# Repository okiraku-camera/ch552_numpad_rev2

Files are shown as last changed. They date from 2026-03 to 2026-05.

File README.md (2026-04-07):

# CH552 Numeric Keypad revision 2

English version is here: [README_en.md](README_en.md)

このリポジトリは、CH552Gマイクロコントローラを使ったシンプルなUSBテンキーを作成するためのハードウェアの作成情報と、このハードウェアを動作させるためのキーボード用ソフトウェアについての情報を含んでいます。

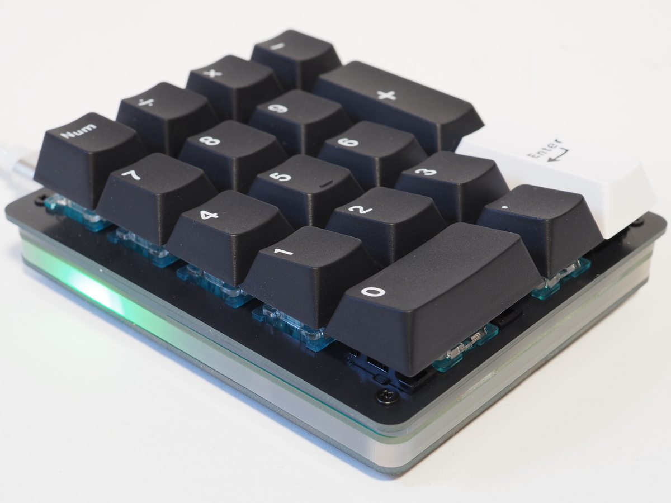
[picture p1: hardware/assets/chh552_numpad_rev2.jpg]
ch5552_numpad_rev2


## ハードウェア
**KiCad 6.0**用のファイル一式、製造に用いたガーバーファイル、アクリルカットのための DXF および PDFファイルが、hardware ディレクトリ内に入っています。

## ソフトウェア
上記のハードウェア用に記述した、マクロキーボードにもなるテンキーです。コアパッケージとして **ch55xDuino** (v0.25) を用いた Arduino 用のスケッチです。また、Arduinoのlibrariesディレクトリに `ch552_keyPad_Library` を配置しておく必要があります。

- `macro_numpad/` : マクロテンキーのファームウェアスケッチ
- `html/` : WebHID 設定用 Web UI (macro_numpad.html)

### webhid を使ったマクロキーボードの実装 (macro_numpad)
テンキーの17キーのうち、NumLock を除いた16キーに、**WebHID** を使って好きな UsageID を割り当てられるようにしています。

メディア操作やマウス操作など、ちょっと特別なコードも設定できます。また、1つのキーに複数の UsageID をまとめて登録できるので、ワンアクションで複数のキー入力をまとめて実行することもできます。

WebHIDのサンプル的な意味合いで記述しました。

### マクロキーボードの設定用webアプリケーション (htmlおよびjavascript)
マクロキーボードとWebHIDで通信し、ブラウザに表示する仮想キーボードとデバイス間とでコードの書込みや読出しを行うためのWebアプリケーションです。

## ライセンス
This project contains hardware and software components.

Copyright (c) Takeshi Higasa, okiraku-camera.tokyo

See [LICENSE](./LICENSE)

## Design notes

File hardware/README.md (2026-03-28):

# ハードウェアについて

English version is here: [README_en.md](README_en.md)

CH552Gマイクロコントローラを使ったシンプルなUSBテンキーです。

このプロジェクトには、PCB、FR-4を使ったプレート、アクリル板を使ったポート部品の、KiCad設計ファイルが含まれています。

製造およびアクリルカットに用いたgerber、DXF、およびPDFファイルも含んでいます。

ハードウェアの設計はKiCAD 6.0で行いました。各ディレクトリ内のKiCADプロジェクトファイルを開くことで、回路構成、PCB構成、各プレートの設計内容を見ることができます。

## PCBおよびプレート
PCB、スイッチをはめ込むtop_plate、底板となる bottom_plate は、材質はFR-4で製造時の厚さ指定は1.6mmです。

### PCB
chh552g を使ったふつうのテンキーを作成するためのPCBです。4列5行構成のスイッチマトリックス回路で、17個のMX互換スイッチを使います。スイッチの取付けには Keilh のスイッチソケット (Hotswap socket) を利用します。

PCBの厚さは1.6mm、PCBのネジ穴径は3mmです。このネジ穴にはM2用の真鍮スペーサーが (途中まで) 入ります。

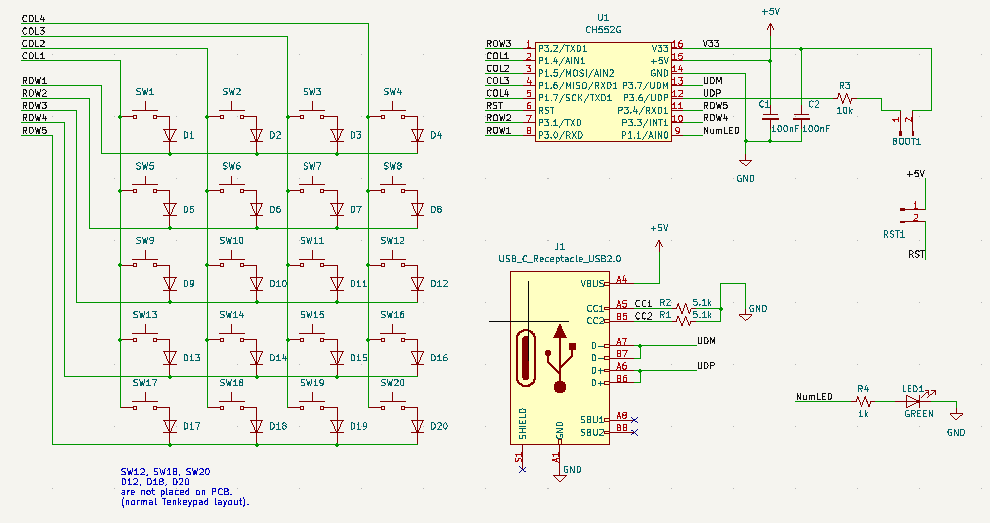
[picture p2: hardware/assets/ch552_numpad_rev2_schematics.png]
回路図

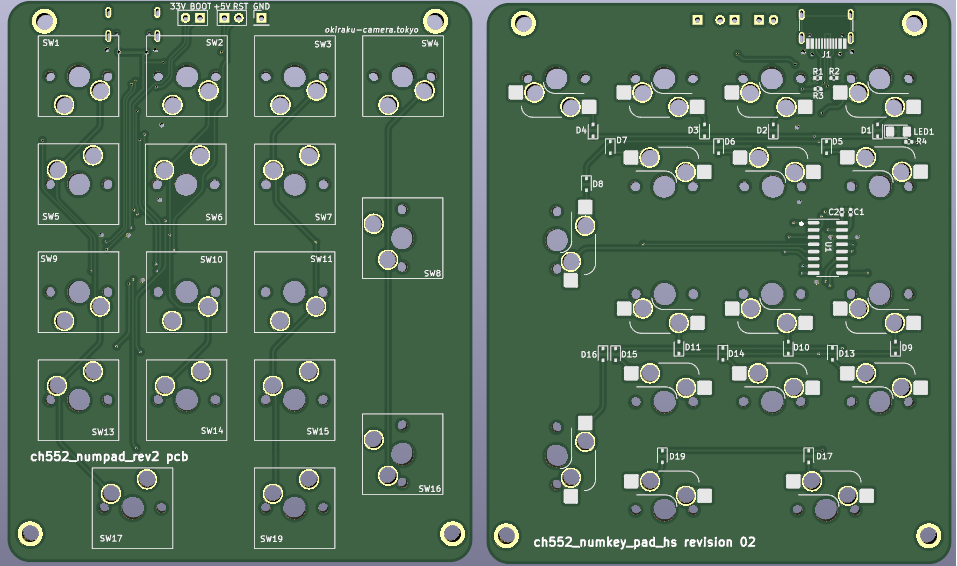
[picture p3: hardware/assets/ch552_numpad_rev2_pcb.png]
PCB


### top_plate
MXスイッチをマウントするためのスイッチプレートです。各スイッチは、13.9mm角の矩形にはめ込みます。MXスイッチの仕様的には14mm角の矩形が求められていますが、実際にスイッチをはめると緩かったりガタつくことがあるので、小さ目にしています。

今回のキーボードはCherryスタイルのプレートマウントスタビライザーを用いるため、そのためのフットプリントを用意しました。

スイッチをはめ込むためのホールは、今回の設計では単純な矩形としていますが、半径0.5mm程度の円弧で丸めた方が割れを防ぐ面で安全です。

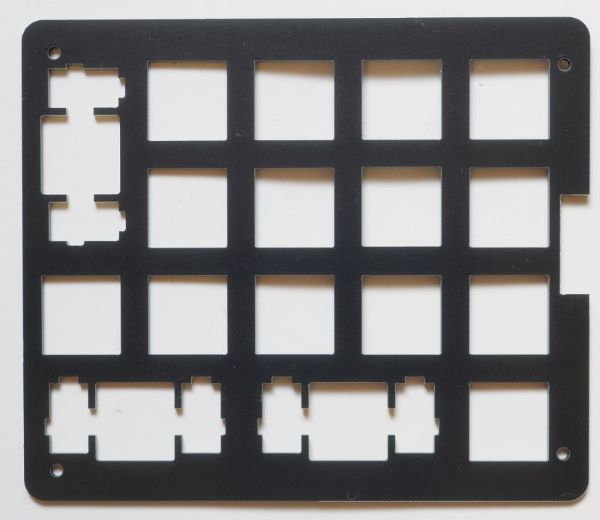
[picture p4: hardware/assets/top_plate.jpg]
top_plate F面


プレートの厚さ1.5mm、ネジ穴径は2.4mmです。

### bottom_plate
キーボードの底板になります。1.6mmのPCBを指定し、B面は導体ゾーンと塗りつぶし禁止エリアを組み合わせた市松模様にしました。

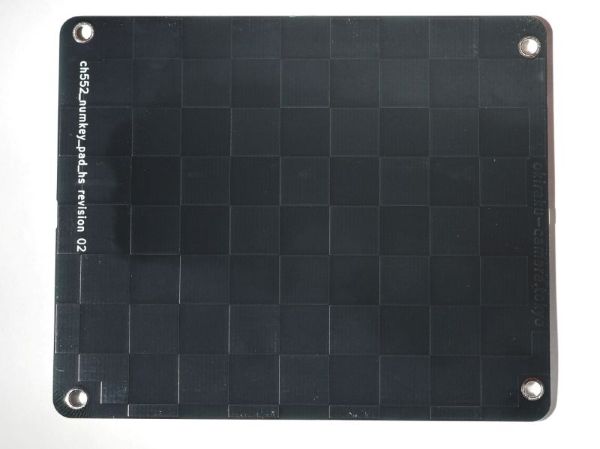
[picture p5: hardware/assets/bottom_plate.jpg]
bottom_plate B面


ネジ穴径は3mmです。

### 注意点

top_plate\libに含まれている プレートマウントスタビライザー用のフットプリント (MX_Plate_Mount_Stabilizer_2U.kicad_mod) と、M2ネジのマウントホール用フットプリント (MountingHole_M2.kicad_mod) にコートヤードを設定しなかったため、Enterキー用のスタビライザーの一部がネジ穴に干渉します。実装後にスタビライザーの一部を切り取ることで対処可能です。

### アクリルサポート
3枚のプレート (PCB, top, bottom) 間のクリアランスを確保するための、アクリル板によるサポート部材です。アクリル板の厚さや部材(透明、半透明、色など) はアクリルカットをやってくれる業者 (Elecrow社など) に対して指定しています。

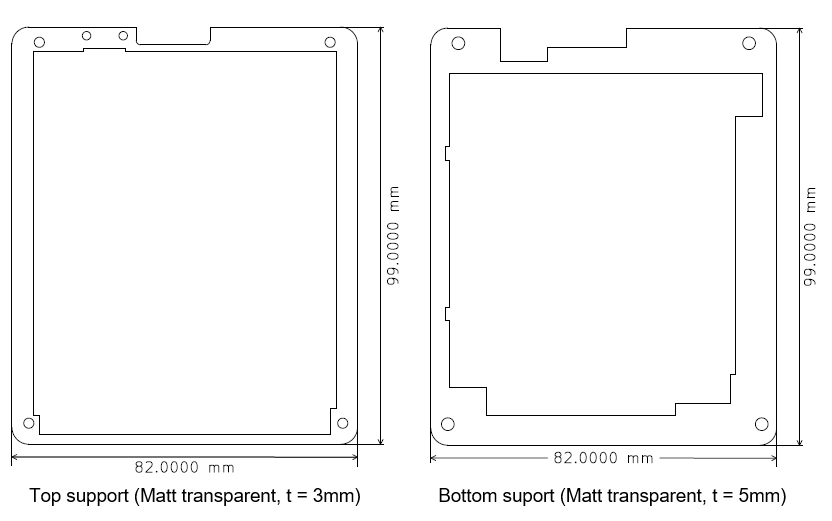
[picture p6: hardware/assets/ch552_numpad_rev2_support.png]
support_dimensions


### top_support
PCBとtop_plate (スイッチプレート)の間に位置する3mm厚のアクリル板です。

top_supportの上側 (top_plate側) には、1mm厚の隙間テープと呼ばれるウレタンスポンジのテープを貼ることで、ソケットを用いるスイッチに必要な4mm弱のクリアランスを確保しています。

このPCBで使っているUSBレセプタクルの固定用ポストの高さは2.0mmであり、PCBのF面側に若干突き出します。アクリル板との干渉を防ぐため、top_support の該当位置に小さな穴を2つ用意しています。

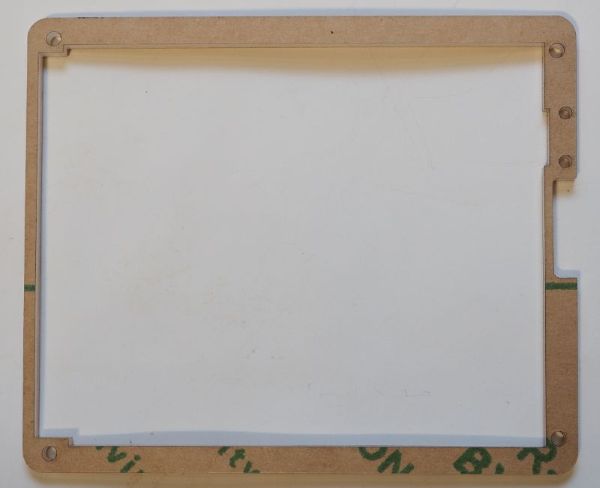
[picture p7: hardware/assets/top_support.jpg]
top_support


カットされたアクリル板は、写真のように保護紙が貼られた状態で納品されます。

top_supportのネジ穴にはM2ネジを通しますが、ネジ穴径は工作精度などを考慮して 2.4mmとしています。

### bottom_support
PCBとbottom_plateの間に入る5mm厚のアクリル板を加工したサポート部材です。PCBのB面に実装するUSBコネクタやスイッチソケットと、底板のあいだには約5mmのクリアランスが必要です。

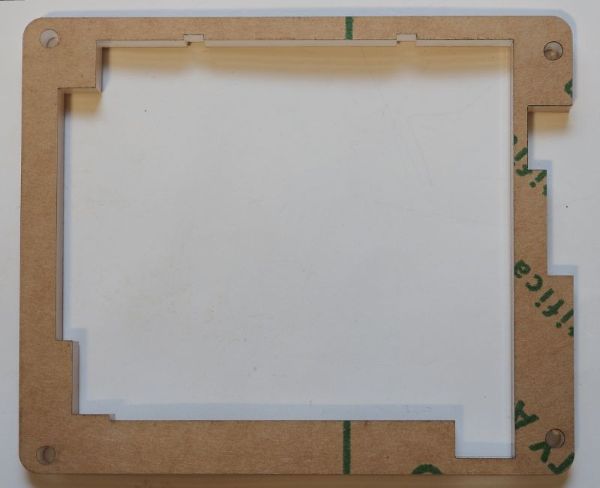
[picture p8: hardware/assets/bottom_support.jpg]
bottom_support


bottom_supportのネジ穴は、M2ネジ用の真鍮スペーサーの外形と同じ3.0mmを指定しています。

## 組み立て
以下の図のように、各プレート、サポートをネジとスペーサーで固定します。

4mm長のM2ネジをねじ込んだ状態のスペーサーを底側から挿入すると、PCBの途中まで達します。その状態でpcbの上に top_supportとtop_plate を置き、上からネジで締め込みます。隙間テープは、top_supportの上側に事前に貼り付けておきます。

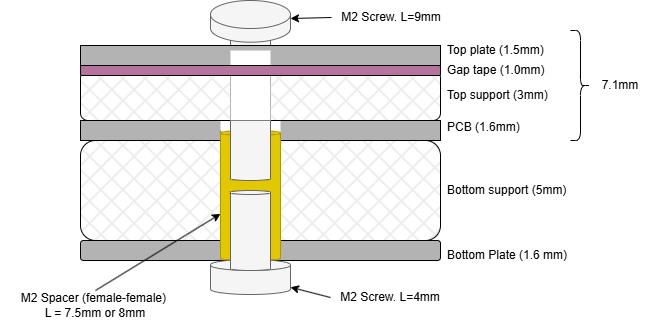
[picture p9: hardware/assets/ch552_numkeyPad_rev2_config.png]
組み立て


bottom_plate, bottom_supportのネジ穴径が3.0mmであるため、組み立て時にはスペーサーを無理やりはめ込むような感触になります。しかしながら、組み立て時に全体を持ち上げてもスペーサーが落下することがないので、作業しやすくなります。

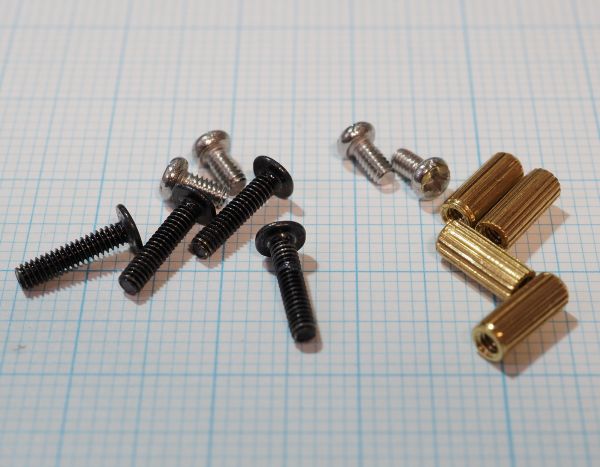
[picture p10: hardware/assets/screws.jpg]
ネジとスペーサー


*組み立てに用いるネジとスペーサー*

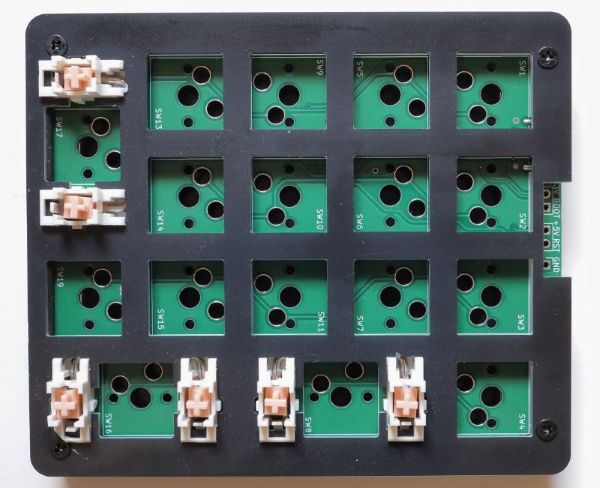
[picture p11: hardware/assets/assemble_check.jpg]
組み立てチェック


*仮組みして、スタビライザーがPCBに接触したり、干渉しないことを確認*

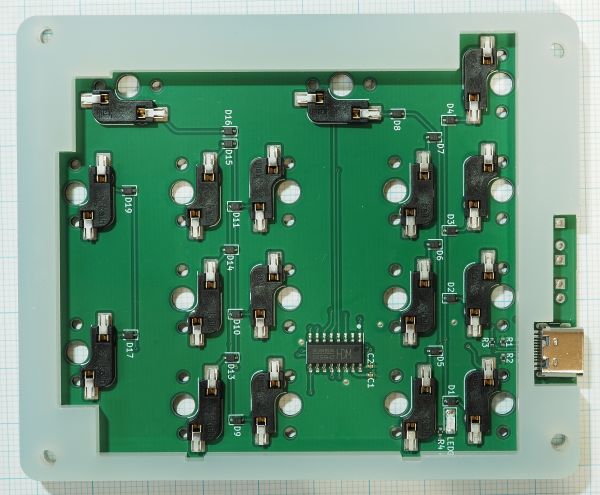
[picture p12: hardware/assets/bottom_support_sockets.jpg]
bottom_supportの確認


*スイッチソケットとbottom_supportが干渉しないことを確認*

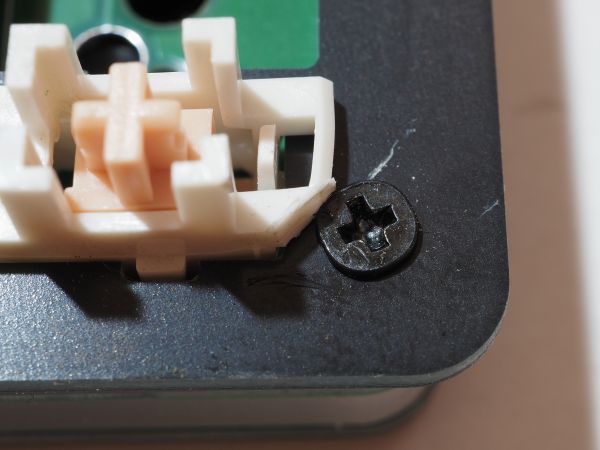
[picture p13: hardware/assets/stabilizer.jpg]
スタビライザーの加工


*Enterキー位置のネジ穴と干渉するため、スタビライザーをわずかにカット*

スタビライザーの取り付け (https://www.youtube.com/watch?v=y5GvuZy3Fyg)

*スタビライザーの取り付け動画*

## ファームウェアの更新について
C552の **P3.6ピンを+3.3Vでプルアップした状態で電源を投入**すると、CH552はブートローダーモードで開始し、数秒間その状態を保持します。そのタイミングでファームウェアをUSB経由で送信することで、ファームウェアを更新できます。

このPCBでは P3.6(UDP)のプルアップがしやすいよう基板の上端にBOOTと33Vという2つのスルーホールパッドを用意しています。2つのパッドをピンセットなどで接続した状態で USBケーブルを接続することで、ブートローダーモードが開始します。ファームウェアの転送中もこれらのパッドを接続したままで問題ないようです。

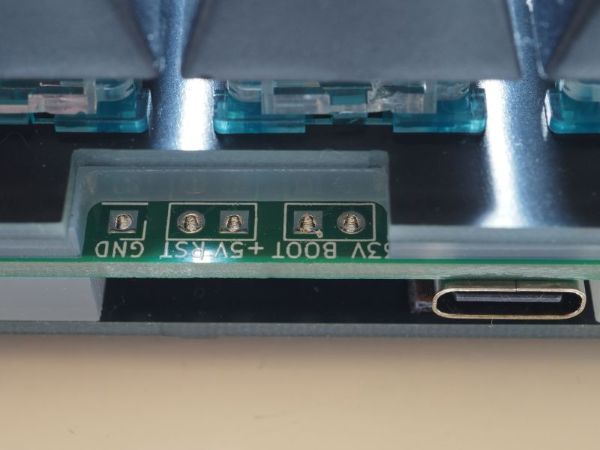
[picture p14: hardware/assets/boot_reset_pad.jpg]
BOOTおよびリセット用のパッド


なお、ファームウェアのアップロードが完了しても自動的にリスタートしないため、BOOTの隣にあるリセット用のパッド (RSTと+5V) を接続してハードウェアリセットをかける必要があります。こちらについても、ピンセットでつまんでやる感じです。

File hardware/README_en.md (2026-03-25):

# About hardware

A simple USB numeric keypad based on the CH552G microcontroller.

The project includes KiCad design files for the PCB, FR-4 plates, and acrylic support parts.

Gerber, DXF, and PDF files used for manufacturing and acrylic cutting are also provided.

The hardware was designed using KiCAD 6.0. By opening the KiCAD project files in each directory, you can view the circuit design, PCB layout, and plate designs.

For the PCB and plates, the Gerber files used for ordering are included. For the acrylic support parts, the directory contains the DXF files and PDF dimension drawings used for acrylic cutting orders.

## PCB and Plates
The PCB, the top plate (switch plate), and the bottom plate are all made of FR‑4 with a specified thickness of 1.6 mm.

### PCB

This PCB is designed for building a simple numeric keypad using the CH552G. It uses a 4‑column × 5‑row switch matrix and supports 17 MX‑compatible switches. Kailh hot‑swap sockets are used for mounting the switches.

The PCB thickness is 1.6 mm, and the screw hole diameter is 3 mm. M2 brass spacers are designed to fit partially into these holes.

schematics
PCB

### top_plate
This is the switch plate for mounting MX switches. Each switch fits into a 13.9 mm square cutout. Although the MX specification calls for a 14 mm square, a slightly smaller size helps reduce looseness and wobble when inserting switches.

Since this keyboard uses Cherry‑style plate‑mount stabilizers, the corresponding footprints are included.
The switch cutouts are simple rectangles in this design, but adding small fillets (around 0.5 mm radius) is safer to prevent cracking.
The plate thickness is 1.5 mm, and the screw hole diameter is 2.4 mm.

top_plate F side

### bottom_plate
This is the bottom plate of the keyboard. The PCB thickness is specified as 1.6 mm.

The B-side copper layer uses a checkerboard pattern created with copper zones and keep-out areas.

bottom_plate B side

The screw hole diameter is 3 mm.

### Notes

Because the footprints for the plate‑mount stabilizer (MX_Plate_Mount_Stabilizer_2U.kicad_mod) and the M2 mounting hole (MountingHole_M2.kicad_mod) in top_plate/lib do not define courtyards, part of the Enter‑key stabilizer interferes with a screw hole. This can be resolved by trimming a small portion of the stabilizer after assembly.

### Acrylic Supports
These acrylic support parts ensure proper clearance between the three plates (PCB, top, bottom). The acrylic thickness and material (clear, frosted, colored, etc.) are specified when ordering from acrylic‑cutting services such as Elecrow.

acrylic support

### top_support
This is a 3 mm thick acrylic plate placed between the PCB and the top plate.
A 1 mm‑thick urethane “gap tape” is applied to the top side (toward the top plate) to secure the nearly 4 mm clearance required for switches using hot‑swap sockets.
M2 screws pass through the top_support, and the screw hole diameter is set to 2.4 mm to account for machining tolerances.

The USB receptacle used on this PCB has 2.0 mm mechanical posts, which protrude slightly from the front (F) side of the board. To prevent interference with the acrylic top plate, two small clearance holes are provided at the corresponding locations on the top_support piece.

top_support

The laser‑cut acrylic plates are delivered with protective paper applied, as shown in the photo.

### bottom_support
This is a 5 mm thick acrylic support placed between the PCB and the bottom plate. Approximately 5 mm of clearance is required between the USB connector and switch sockets on the PCB’s B‑side and the bottom plate.
The screw hole diameter is 3.0 mm, matching the outer diameter of M2 brass spacers.

bottom_support

## Assembly
As shown in the diagram below, the plates and supports are fixed together using screws and spacers.

Insert spacers with 4 mm M2 screws pre‑threaded into them from the bottom side; they will reach partway into the PCB. Place the top_support and top_plate on the PCB, then tighten screws from above. The gap tape should be applied to the top side of the top_support beforehand.

Assembly

Because the screw holes in the bottom_plate and bottom_support are 3.0 mm, inserting the spacers during assembly may feel slightly tight. However, once inserted, the spacers will not fall out even if the assembly is lifted, making the process easier.

spacers and screws

brass spacers and scrwes.

bottom_support and sockets

The cutout in bottom_support is designed to prevent interference with the switch socket.

Attach stabilizer (https://www.youtube.com/watch?v=y5GvuZy3Fyg)

*Video : Attach stabilizer to switch plate*

## Firmware Update Procedure

When the P3.6 pin of the CH552 is pulled up to +3.3V at power‑on, the chip enters bootloader mode and remains in that state for several seconds. During this window, you can upload new firmware over USB.

On this PCB, two through‑hole pads labeled BOOT and 3.3V are placed at the top edge to make it easy to pull up P3.6 (UDP). By shorting these two pads with tweezers and then connecting the USB cable, the CH552 will start in bootloader mode. It is safe to keep the pads shorted for the entire duration of the firmware transfer.

Boot and Reset pads

Note that the chip does not automatically restart after the upload completes. To start the newly written firmware, you need to perform a hardware reset by shorting the RST and +5V pads located next to the BOOT pads. This is also done by briefly touching the two pads with tweezers.

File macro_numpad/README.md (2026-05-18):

# macro_numpad

English version is here: [README_en.md](README_en.md)

## 概要

macro_numpad は、CH552G をベースにしたプログラマブルなテンキー / マクロキーパッドです。
デフォルトでは通常のテンキーとして動作し、Web UI でキーマップやマクロをカスタマイズできます。

## 主な機能

- デュアルモード: テンキーモードまたはマクロパッドモード（スイッチ0 に割り当てた NumLockまたはFn で制御）
- 2レイヤーのキーマップシステム（Num/Fn 動作）
- 最大10個のマクロ（m0-m9）
- 修飾キー組み合わせ対応（Shift/Ctrl/Alt/Win）
- NVM（内蔵 EEPROM, 128 bytes）への永続保存

## ハードウェア概要

- MCU: CH552G（USB 2.0 Full Speed）
- マトリクス: 4x5 配置
- 実装スイッチ数: 17
- スイッチ0 (NumLockキー) 
- 多機能 LED:
  - テンキーモード: NumLock インジケータ
  - マクロパッドモード: レイヤーインジケータ

## ソフトウェア構成

- ファームウェアスケッチ（このディレクトリ）: `macro_numpad.ino`
- Web UI（リポジトリルート `html/`）: `../html/macro_numpad.html`, `../html/macro_numpad.js`, `../html/style.css`
- 共通 CH552 キーパッド用ソースは Arduino ライブラリ `ch552_keyPad_Library` で提供されます。

## 使い方

### はじめて使うとき

1. パソコンに macro_numpad を接続します。
2. `../html/macro_numpad.html` をブラウザで開きます。
3. 画面の「Connect to Keyboard」を押して、表示されたデバイスを選びます。
4. 画面上のキーをクリックして、好きなキー操作やマクロを割り当てます。
5. 「Write」操作で本体に保存します。

### ふだんの使い方

- スイッチ0にFnキー機能を割り当てている場合、Num キー（スイッチ0）でテンキー動作とマクロ動作を切り替えられます。
- 保存した内容は次回接続時もそのまま使えます。
- マクロ実行中に別のキーを押すと、そのマクロは止まります。

### 困ったとき

- デバイスが見つからない場合は、USB ケーブルの抜き差し後に再接続してください。
- 接続できない場合は、ブラウザを再読み込みして再度「Connect to Keyboard」を実行してください。

### WebUI 詳細ガイド

詳しい画面説明は次を参照してください。

- 日本語: `../html/README.md`
- English: `../html/README_en.md`

## ビルド

このファームウェアは次の環境でビルドできます。

- Visual Studio Code + vscode-arduino 拡張
- arduino-cli
- CH55xDuino v0.25
- ch552_keyPad_Library（Arduino の user libraries ディレクトリ）

### ボード設定

ボード設定メニューで次を選択してください。

- USB Settings: `USER CODE w/ 148B USB ram`

このオプションは、HID エンドポイントに必要な USB RAM を割り当てます。

## 技術メモ

- キーマップとマクロは別々に保存されます。
- マクロ再生中にいずれかのキーが押されると、マクロ送信は即座に中断されます。
- ブートローダ起動時にデバイスが一時的に切断される場合があります。

## ライセンス

このプロジェクトは MIT License の下で公開されています。

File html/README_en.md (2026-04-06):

# macro_numpad WebUI Guide

## Overview

This document explains how to configure keymaps and macros on the device using `macro_numpad.html`.
`macro_numpad.js` handles WebHID communication and UI behavior, and `style.css` controls the styling.

## Requirements

- WebHID-capable browser (Chrome / Edge recommended)
- macro_numpad device connected via USB
- All files in this `html` directory

## Startup

1. Open `macro_numpad.html` in your browser.
2. Click "Connect to Keyboard".
3. Select your device in the device picker dialog.
4. After connection, keymap and macros are loaded automatically.

## Screen Layout

- Connect button: starts WebHID connection.
- Keymap operation buttons:
  - Read Keymap
  - Write Keymap
  - Read Macros
  - Write Macros
- Macro editor button: opens the macro editor dialog.
- Keypad area: shows current assignments and pending status.
- Utility buttons:
  - Reset to Default
  - Start Bootloader
  - Read NVM
  - macro ptrs
- Log area: shows operation results, communication errors, and debug output.

## Keymap Workflow

1. Click the target key in the keypad area.
2. Select a key in the key selection dialog.
3. Enable modifier toggles (Shift/Ctrl/Alt/Win) if needed.
4. A pending mark (⏳) appears after local changes.
5. Click "Write Keymap" to apply changes to the device.

### Switch 0 Configuration

- Switch 0 is reserved for mode control.
- Use the special dialog to choose:
  - Num: Numeric keypad mode
  - Fn: Macro pad mode (layer toggle)

## Macro Workflow

1. Click "Edit Macros" to open the macro editor.
2. Select a macro slot (m0-m5).
3. Add key codes in sequence.
4. Add delay codes (100ms/500ms/1sec) if needed.
5. Use "Delete Last" or "Clear" to fix mistakes.
6. Click "Write Macros" to save macros to the device.

### Macro Assignment

1. Open key assignment dialog for the target key.
2. Select macro trigger key (m0-m5).
3. Click "Write Keymap" to save assignment.

### Runtime Abort

If any key is pressed while a macro is being sent, macro transmission is stopped immediately.

## NVM Operations

- Read Keymap: loads key assignments from device NVM.
- Read Macros: loads macro data from device NVM.
- Read NVM: dumps raw NVM data in hex (for debugging).
- macro ptrs: shows macro pointer table (for debugging).
- Reset to Default: restores default keymap and clears macros.

## Important Notes

- If the device is unplugged or reset during operation, actions become invalid. Reconnect the device.
- Keymap writes and macro writes are separate operations. Save both when necessary.
- Starting bootloader may disconnect the device temporarily.

## Troubleshooting

### Device does not appear

- Verify your USB cable supports data transfer.
- Verify your browser supports WebHID.
- Check if another application is currently using the device.

### Write operation fails

- Confirm that connection is established first.
- Check log messages (Timeout, Version mismatch, etc.).
- Try "Read Keymap" once, then edit and write again.

### Macro behavior is unexpected

- Verify macro slot content and key assignment.
- Check whether too many delays make execution feel slow.
- Confirm macro data does not exceed the 45-byte macro area.

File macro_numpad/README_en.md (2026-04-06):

# macro_numpad

## Overview

macro_numpad is a programmable numeric keypad / macro keypad based on CH552G.
By default, it works as a standard numeric keypad, and you can customize keymaps and macros using the Web UI.

## Main Features

- Dual mode: numeric keypad or macro pad (controlled by switch 0)
- 2-layer keymap system (Num/Fn behavior)
- Up to 10 macros (m0-m9)
- Modifier combination support (Shift/Ctrl/Alt/Win)
- Persistent storage in NVM (built-in EEPROM, 128 bytes)

## Hardware Summary

- MCU: CH552G (USB 2.0 Full Speed)
- Matrix: 4x5 positions
- Implemented switches: 17
- Switch 0: mode control (Num/Fn)
- Multi-function LED:
  - Numeric mode: NumLock indicator
  - Macro pad mode: layer indicator

## Software Structure

- Firmware sketch (this directory): `macro_numpad.ino`
- Web UI (repository root `html/`): `../html/macro_numpad.html`, `../html/macro_numpad.js`, `../html/style.css`
- Common CH552 keypad source files are provided by the `ch552_keyPad_Library` Arduino library.

## Usage

### Quick Start

1. Open `../html/macro_numpad.html` in a WebHID-capable browser.
2. Connect the device from "Connect to Keyboard".
3. Edit keymap/macros and write them to device.

### Detailed WebUI Guide

Detailed operation steps are documented here:

- Japanese: `../html/README.md`
- English: `../html/README_en.md`

## Build

This firmware can be built with:

- Visual Studio Code with the vscode-arduino extension
- arduino-cli
- CH55xDuino v0.25.
- ch552_keyPad_Library (arduino user libraries directory). 

### Board Configuration

In the board configuration menu, select:

- USB Settings: `USER CODE w/ 148B USB ram`

This option allocates the USB RAM required for HID endpoints.

## Technical Notes

- Keymap and macros are saved separately.
- Macro transmission is aborted immediately when any key is pressed during macro playback.
- Starting bootloader may disconnect the device temporarily.

## License

This project is released under the MIT License.

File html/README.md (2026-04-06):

# macro_numpad WebUI 使い方ガイド

English version is here: [README_en.md](README_en.md)

## 概要

このドキュメントでは、`macro_numpad.html` を使ってキーボード本体のキーマップ・マクロを設定する手順を説明します。
`macro_numpad.js` がWebHID通信と画面制御を担当し、`style.css` がUIの見た目を担当します。

## 動作要件

- WebHID対応ブラウザ（Chrome / Edge 推奨）
- USB接続された macro_numpad デバイス
- この `html` ディレクトリ内ファイル一式

## 起動方法

1. `macro_numpad.html` をブラウザで開きます。
2. 画面上部の「キーボードに接続」を押します。
3. デバイス選択ダイアログで対象デバイスを選びます。
4. 接続に成功すると、キーマップとマクロが自動読み出しされます。

## 画面構成

- 接続ボタン: WebHIDでデバイス接続を開始します。
- キーマップ操作ボタン:
  - キーマップを読み出す
  - キーマップを書き込む
  - マクロを読み出す
  - マクロを書き込む
- マクロ編集ボタン: マクロエディタを開きます。
- テンキー表示領域: キーの現在割り当てと変更状態を表示します。
- 補助ボタン:
  - デフォルトにリセット
  - ブートローダー開始
  - NVMを読み出す
  - macro ptrs
- ログ領域: 操作結果、通信エラー、デバッグ情報を表示します。

## キーマップ設定の流れ

1. 変更したいキーをテンキー表示領域でクリックします。
2. キー選択ダイアログからキーを選びます。
3. 必要なら修飾キー（Shift/Ctrl/Alt/Win）を有効にします。
4. 設定後、キーに保留マーク（⏳）が表示されます。
5. 「キーマップを書き込む」を押してデバイスへ反映します。

### スイッチ0の設定

- スイッチ0は通常キーではなくモード制御用です。
- 特殊ダイアログで以下を選びます。
  - Num: テンキーモード
  - Fn: マクロパッドモード（レイヤー切替）

## マクロ設定の流れ

1. 「マクロを編集する」を押してマクロエディタを開きます。
2. 編集対象のスロット（m0〜m5）を選択します。
3. キー群からコードを順番に追加します。
4. 必要に応じて遅延コード（100ms/500ms/1sec）を追加します。
5. 間違えた場合は「最後を削除」または「クリア」で修正します。
6. 「マクロを書き込む」を押してデバイスに保存します。

### マクロ割り当て

1. 通常のキー設定ダイアログで割り当て対象キーを選びます。
2. マクロトリガー（m0〜m5）を選択します。
3. 「キーマップを書き込む」で保存します。

### 実行中断

マクロ送信中にいずれかのキーを押すと、送信中のマクロは停止します。

## NVM関連操作

- キーマップを読み出す: デバイスNVMのキー設定を読み込みます。
- マクロを読み出す: デバイスNVMのマクロデータを読み込みます。
- NVMを読み出す: 生データを16進表示します（デバッグ用途）。
- macro ptrs: マクロ先頭ポインタ情報を表示します（デバッグ用途）。
- デフォルトにリセット: キーマップ初期状態とマクロ消去を行います。

## 重要な注意点

- 接続中デバイスが抜線・リセットされた場合、操作は無効になります。再接続してください。
- キーマップ変更とマクロ変更は別保存です。必要に応じて両方書き込んでください。
- ブートローダー開始を実行すると、デバイスが一時的に切断されることがあります。

## トラブルシューティング

### デバイスが表示されない

- USBケーブルのデータ通信対応を確認してください。
- ブラウザのWebHID対応状況を確認してください。
- 他アプリが同じデバイスを占有していないか確認してください。

### 書き込みできない

- 先に接続が成功しているか確認してください。
- ログ欄のエラー（Timeout、Version mismatch など）を確認してください。
- 一度「キーマップを読み出す」後に再編集して再実行してください。

### マクロが期待どおり動かない

- マクロスロットの中身と割り当て先キーを再確認してください。
- 遅延コードの入れすぎで体感上遅くなっていないか確認してください。
- マクロ容量上限（45バイト）を超えていないか確認してください。

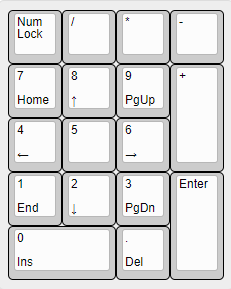
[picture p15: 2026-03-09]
hardware/assets/numkeyPad.PNG

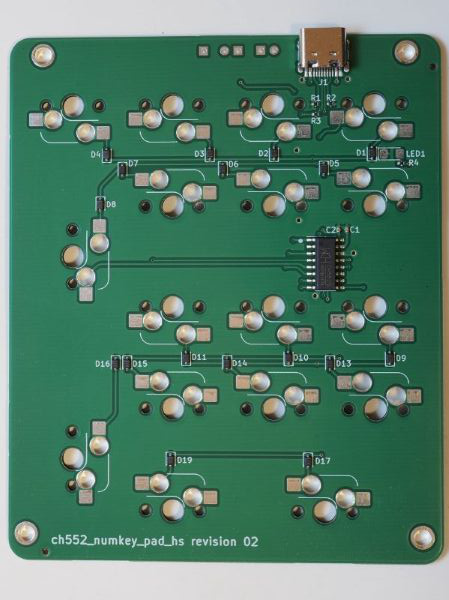
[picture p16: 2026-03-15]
hardware/assets/pcb_b_side.jpg

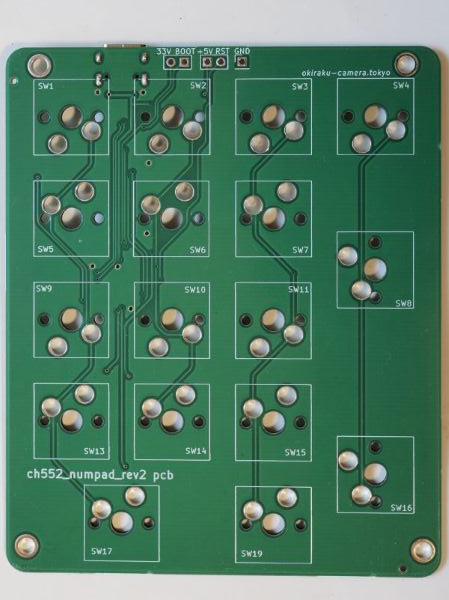
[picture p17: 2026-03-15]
hardware/assets/pcb_f_side.jpg

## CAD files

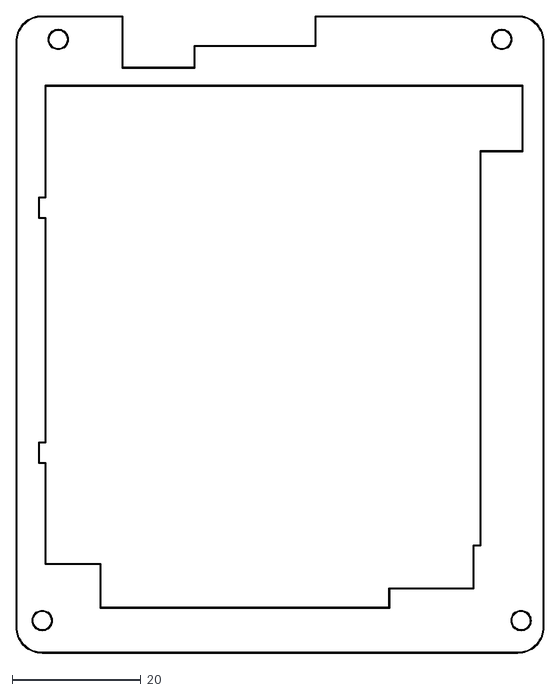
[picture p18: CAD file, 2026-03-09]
hardware/bottom_support/bottom_support.dxf
82.1 x 99.1

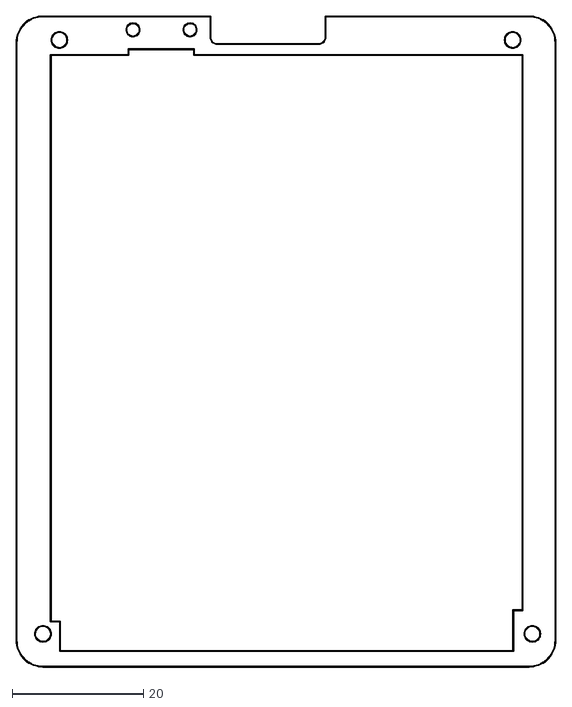
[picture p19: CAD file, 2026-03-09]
hardware/top_support/top_support.dxf
82.1 x 99.1

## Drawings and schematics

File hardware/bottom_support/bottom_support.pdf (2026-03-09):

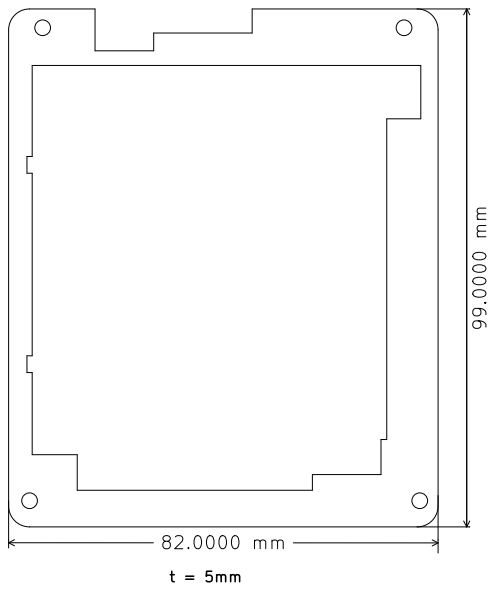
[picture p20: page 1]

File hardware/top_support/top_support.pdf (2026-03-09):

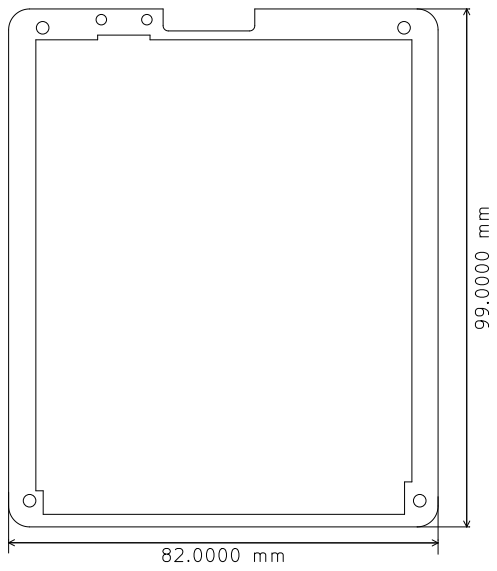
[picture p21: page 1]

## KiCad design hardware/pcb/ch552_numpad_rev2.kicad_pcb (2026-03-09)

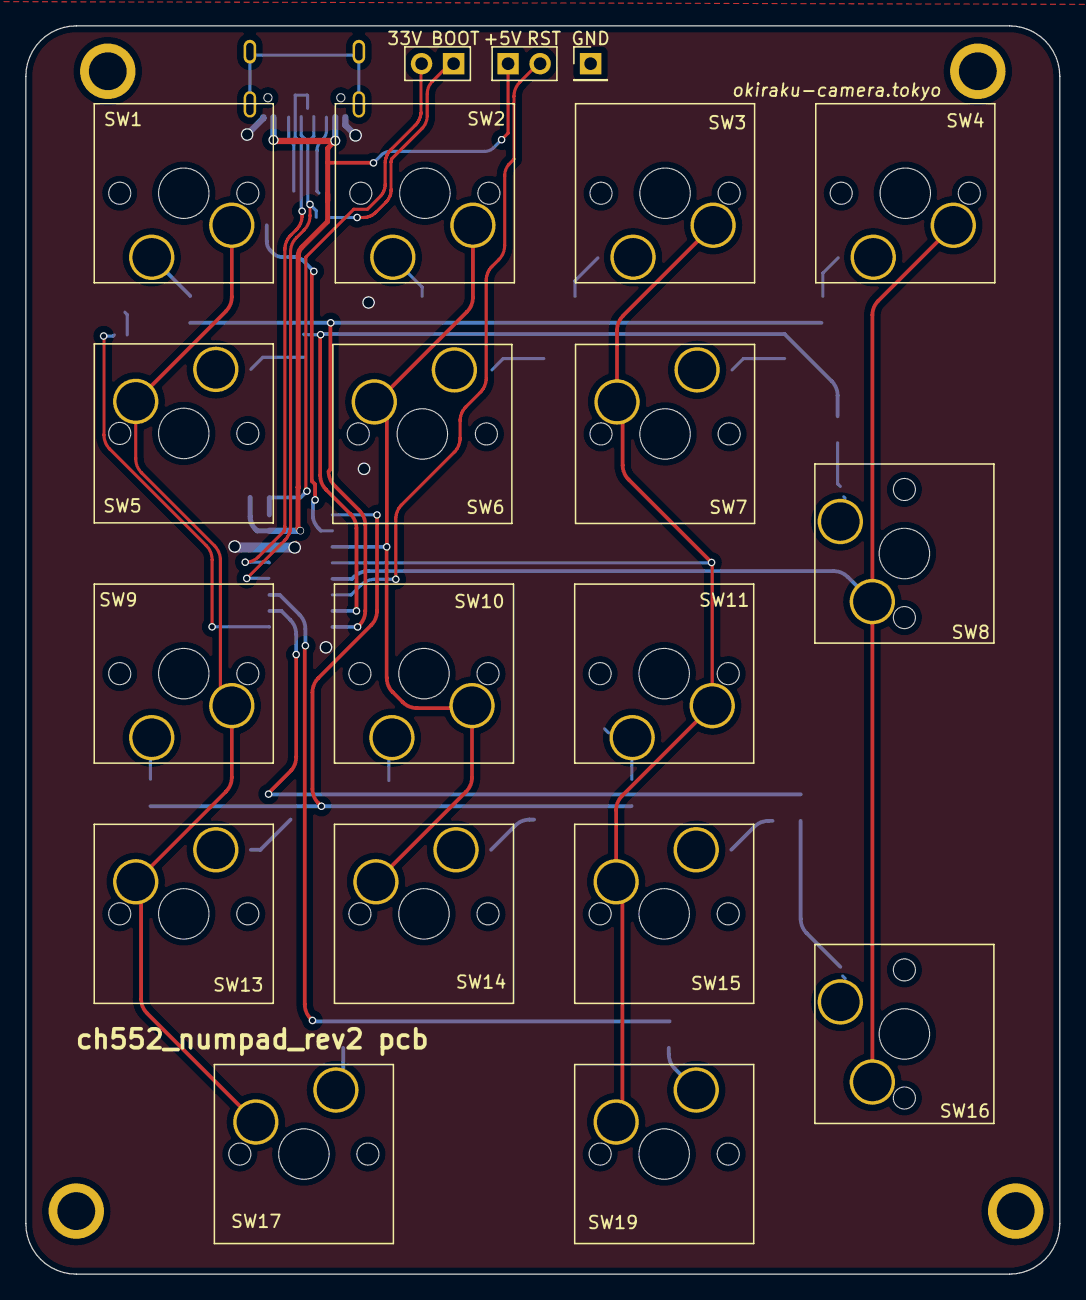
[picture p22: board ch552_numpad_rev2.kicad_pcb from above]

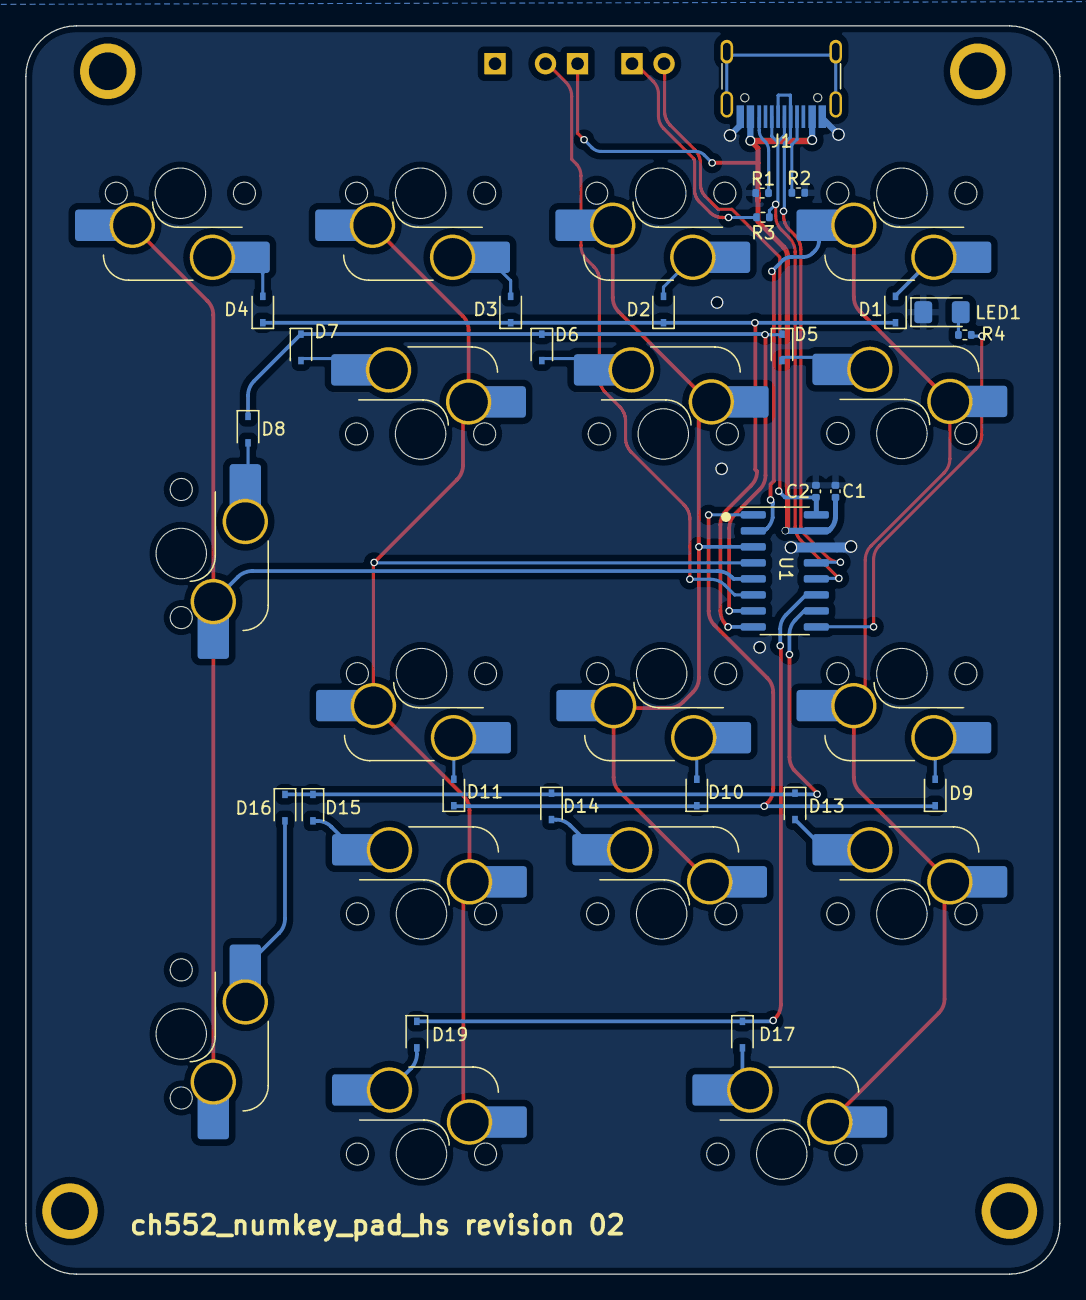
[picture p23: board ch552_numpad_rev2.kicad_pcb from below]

Board: 2 copper layers, 82.0 x 99.0 mm, 45 parts (26 on the bottom side), 37 nets.

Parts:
BOOT1: Conn_01x02_Male; PinHeader_1x02_P2.54mm_Vertical
C1, C2: 100nF; C_0402_1005Metric
D1, D2, D3, D4, D5, D6, D7, D8, D9, D10, D11, D13, D14, D15, D16, D17, D19: 1N4148WS; D_SOD-323
J1: USB_C_Receptacle_USB2.0; USB_C_Receptacle_304J-BCP16
LED1: GREEN; LED_1206_3216Metric_Pad1.42x1.75mm_HandSolder
R1, R2: 5.1k; R_0402_1005Metric
R3: 10k; R_0402_1005Metric
R4: 1k; R_0402_1005Metric
RST1: Conn_01x02_Male; PinHeader_1x02_P2.54mm_Vertical
SW1, SW2, SW3, SW4, SW5, SW6, SW7, SW9, SW10, SW11, SW13, SW14, SW15, SW19: SW_Push; SW_Hotswap_Kailh_MX_Plated_1.00u
SW8, SW16, SW17: SW_Push; SW_Hotswap_Kailh_MX_Plated_2.00u
U1: CH552G; SOP-16_3.9x9.9mm_P1.27mm

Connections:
+5V: C1.1, J1.A4 (VBUS), J1.A9 (VBUS), J1.B4 (VBUS), J1.B9 (VBUS), RST1.1, U1.15 (+5V)
/CC1: J1.A5 (CC1), R2.1
/CC2: J1.B5 (CC2), R1.1
/COL1: SW1.1, SW5.1, SW9.1, SW13.1, SW17.1, U1.2 (P1.4/AIN1)
/COL2: SW2.1, SW6.1, SW10.1, SW14.1, U1.3 (P1.5/MOSI/AIN2)
/COL3: SW3.1, SW7.1, SW11.1, SW15.1, SW19.1, U1.4 (P1.6/MISO/RXD1)
/COL4: SW4.1, SW8.1, SW16.1, U1.5 (P1.7/SCK/TXD1)
/NumLED: R4.1, U1.9 (P1.1/AIN0)
/ROW1: D1.1 (K), D2.1 (K), D3.1 (K), D4.1 (K), U1.8 (P3.0/RXD)
/ROW2: D5.1 (K), D6.1 (K), D7.1 (K), D8.1 (K), U1.7 (P3.1/TXD)
/ROW3: D9.1 (K), D10.1 (K), D11.1 (K), U1.1 (P3.2/TXD1)
/ROW4: D13.1 (K), D14.1 (K), D15.1 (K), D16.1 (K), U1.10 (P3.3/INT1)
/ROW5: D17.1 (K), D19.1 (K), U1.11 (P3.4/RXD1)
/RST: RST1.2, U1.6 (RST)
/UDM: J1.A7 (D-), J1.B7 (D-), U1.13 (P3.7/UDM)
/UDP: J1.A6 (D+), J1.B6 (D+), R3.1, U1.12 (P3.6/UDP)
/V33: BOOT1.2, C2.1, U1.16 (V33)
GND: C1.2, C2.2, J1.A1 (GND), J1.A12 (GND), J1.B1 (GND), J1.B12 (GND), LED1.1 (K), R1.2, R2.2, U1.14 (GND)
unnamed: BOOT1.1, R3.2
unnamed: D1.2 (A), SW1.2
unnamed: D2.2 (A), SW2.2
unnamed: D3.2 (A), SW3.2
unnamed: D4.2 (A), SW4.2
unnamed: D5.2 (A), SW5.2
unnamed: D6.2 (A), SW6.2
unnamed: D7.2 (A), SW7.2
unnamed: D8.2 (A), SW8.2
unnamed: D9.2 (A), SW9.2
unnamed: D10.2 (A), SW10.2
unnamed: D11.2 (A), SW11.2
unnamed: D13.2 (A), SW13.2
unnamed: D14.2 (A), SW14.2
unnamed: D15.2 (A), SW15.2
unnamed: D16.2 (A), SW16.2
unnamed: D17.2 (A), SW17.2
unnamed: D19.2 (A), SW19.2
unnamed: LED1.2 (A), R4.2

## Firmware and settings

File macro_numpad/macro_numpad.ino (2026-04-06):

/**
 * macro_numpad.ino main sketch of Numeric or Macro Keypad program using ch552g.
 * Copyright (c)  Takeshi Higasa, okiraku-camera.tokyo
 * 
 * This software is released under the MIT License.
 * http://opensource.org/licenses/mit-license.php
 * 
 */
#include "USB_hid_composite.h"
#include "hid_keycode.h"
#include "ch552_watchdog.h"
#include "nvm_keymap.h"	

#include "hardware_config.h"	// for hardware dependent constants.

#define numlock_led  11
const uint8_t cols[] = {14, 15, 16, 17};
const uint8_t rows[] = {30, 31, 32, 33, 34};
const uint8_t row_masks[] = {1, 2, 4, 8, 0x10};

// NumLock led connected to P1.1 
#define NUMLOCK_LED_MASK  2

// Initial layout of Numeric keypad.
// This layout is written to NVM on first boot and reset command. User can change the layout by writing to NVM.
const uint16_t text_scan_to_hid[NUM_KEYS] = {
	HID_KEYPAD_NUMLOCK,
	HID_KEYPAD_SLASH,
	HID_KEYPAD_ASTERISK,
	HID_KEYPAD_MINUS,
	HID_KEYPAD_7,
	HID_KEYPAD_8,
	HID_KEYPAD_9,
	HID_KEYPAD_PLUS,
	HID_KEYPAD_4,
	HID_KEYPAD_5,
	HID_KEYPAD_6,
	0,
	HID_KEYPAD_1,
	HID_KEYPAD_2,
	HID_KEYPAD_3,
	HID_KEYPAD_ENTER,
	HID_KEYPAD_0,
	0,
	HID_KEYPAD_PERIOD,
	0
};

// true if sw0 contains numLock code, it means this keyboard is numeric keypad. if false, it is macro keypad. 
bool numeric_keypad = true;

int8_t current_layer = 0;	// 0 or 1. this is used for macropad layer switching.


void write_code_callback(uint8_t sw, uint8_t layer, uint16_t code) {
	if (sw == 0 && code == HID_KEYPAD_NUMLOCK)	// if sw0 is set to numLock code, it is numeric keypad. this is used for initial layout check.
		numeric_keypad = true;
	else if (sw == 0 && code != HID_KEYPAD_NUMLOCK)	// if sw0 is set to other than numLock code, it is macro keypad.
		numeric_keypad = false;
}


// called from USBhandler
void USBStartSuspend() {
	P1 &= ~NUMLOCK_LED_MASK;
}

uint8_t active_macro = 0;	// 0 means no active macro. 1～MACRO_KEY_COUNT means active macro index. this is set when macro key is pressed, and reset when macro code is sent.
uint8_t macro_index = 0;	// Index tracking the current position within the macro sequence referenced by activa_macro.
int8_t macro_delay_count = 0;	// Counter for tracking delay steps in macro execution, used when processing delay codes within a macro sequence.

void key_event(uint8_t switch_num, uint8_t state) {
	if (switch_num < 1 || switch_num > NUM_KEYS )
		return;

	if (active_macro) {
		if (state) {
			macro_index = 0;
			macro_delay_count = 0;
			active_macro = 0;
			kbd_releaseAll();
		}
		return;
	}	
	// get a assigned code of switch_num.
	uint16_t hidcode = read_nvm_code(switch_num - 1, current_layer);
	// 
	if (hidcode != 0) {
		uint8_t code = (uint8_t)hidcode & 0xff;
		uint8_t mod = (hidcode >> 8) & 0xff; 
		if ((code == HID_X_FN1) && state) {	// layer switch key. this is not sent to host, but used for layer switching.
			current_layer ^= 1;
			return;
		}
		if (IS_MACRO_KEYCODE(code)) {
			if (state) {
				active_macro = hidcode - MACRO_KEYCODE_BASE;
				if (macro_ptrs[active_macro] == 0) {	// no macro code.
					active_macro = 0;
					return;
				}
				active_macro++;
				macro_index = 0;
				macro_delay_count = 0;
			}
		} else {
			if (mod && state) {
				send_modifiers(mod, 1);
				delay(20);
			}
			send_key(code, state);
			if (mod && !state) {
				delay(20);
				send_modifiers(mod, 0);
			}
		}
	}
}

#define scan_bytes 3
static uint8_t last_stable[scan_bytes];
static uint8_t last_scan[scan_bytes];
void scan() {
	__data uint8_t keys[scan_bytes];
	__data uint8_t key = 0;
	for(uint8_t row = 0; row < sizeof(rows); row++) {
		P3 &= ~row_masks[row];		// select a row.
		if (row & 1)
			keys[key++] |= (~P1 & 0xf0);
		else
			keys[key] = (~P1 >> 4) & 0x0f;
		P3 |= row_masks[row];		// unselect a row.
		delayMicroseconds(30);		// wait for signal to settle. may be needed for stable scan result.
	}
	
	uint8_t n = 0;
	for(uint8_t i = 0; i < sizeof(keys); i++) {
		// check if current and prev scan results are match.
		if (last_scan[i] != keys[i])
			n++;
		last_scan[i] = keys[i];		// save current result as prev result.
	}
	if (n)
		return;	// no match. may be bounced.

	for(key = 0; key < sizeof(keys); key++, n += 8) {
		uint8_t changes = keys[key] ^ last_stable[key];
		last_stable[key] = keys[key];	// save last-stable state.
		if (changes) {
			uint8_t mask = 1;
			for (uint8_t i = 0; i < 8; i++, mask <<=1 )
				if (changes & mask) key_event(n + i + 1, keys[key] & mask ? 1 : 0);
		}
	}
}

// boot loader entry address is defined in ch5xx.h
void enter_bootloader_mode() {
#if defined(BOOT_LOAD_ADDR)
	digitalWrite(numlock_led, 0);
	USB_CTRL = 0;
	EA = 0; // Disabling all interrupts is required.
	TMOD = 0;
	delay(10);
	__asm__("lcall #0x3800"); // Jump to bootloader code
	for(;;) {}
#endif
}

void build_initial_layout() {
	// build initial layout. this is used when nvm is not valid.
	for(int8_t i = 0; i < NUM_KEYS ; i++) {	
		uint16_t code = text_scan_to_hid[i];
		nvm_write_word(KEYMAP_START + (i << 1), code);				// レイヤー0はテンキー
		nvm_write_word(KEYMAP_START + NUM_KEYS * 2 + (i << 1), 0);	// レイヤー1はすべて0
	}
}

// type_macro_strings() is called repeatedly from loop() by 10msec.  
// When a modifier keycode appears in the macro, send the corresponding modifier-on event.
// When the macro reaches its end, if any modifiers were turned on, send modifier-off events for all of them.
// Modifier-off events at the end are sent regardless of the physical modifier state.
void type_macro_strings() {
	static uint8_t mod = 0;
	static uint8_t seg_start_index = 0xff;	// this is used for tracking the start index of a segment when processing segment start and goto codes in macro. 0xff means no segment start encountered yet.	

	if (macro_delay_count > 0) {
		macro_delay_count--;
		return ;
	}

	if (macro_index == 0)
		seg_start_index = 0xff;

	uint16_t macro_base = macro_ptrs[active_macro - 1];
	if (macro_base == 0) {	// no macro code.
		active_macro = 0;
		macro_delay_count = 0;
		seg_start_index = 0xff;
		return ;
	}
	uint8_t code = eeprom_read_byte(macro_base + macro_index);
	if (code == 0) {	// end of macro code.
		active_macro = 0;
		macro_index = 0;
		macro_delay_count = 0;
		mod = 0;
		seg_start_index = 0xff;
		kbd_releaseAll();
		return ;
	}

	if (code == HID_M_SEGSTART) {
		if (seg_start_index == 0xff) {
			seg_start_index = macro_index;
		}
		macro_index++;
		return ;
	}

	if (code == HID_M_GOTO_SEG) {
		macro_index = (seg_start_index == 0xff) ? 0 : seg_start_index;
		return ;
	}

	if (IS_MACRO_DELAY_CODE(code)) {
		switch (code) {
		case HID_M_DELAY100:
			macro_delay_count = 10;	// set delay count for 100ms.
			break;
		case HID_M_DELAY500:
			macro_delay_count = 50;	// set delay count for 500ms.
			break;
		case HID_M_DELAY1000:
			macro_delay_count = 100;	// set delay count for 1000ms.
			break;
		default:
			macro_delay_count = 0;
		}
		macro_index++;
		return ;
	}

	if (IS_MODIFIER_KEYCODE(code)) { 
		mod |= (1 << ((code - HID_MODIFIERS) & 0x7));	// 0～7 for left mods.
		if ((mod & modifiers) & mod) {	// if some modifiers are already on, send the new modifiers state.	
			send_modifiers(mod, false);
		} else {
			send_modifiers(mod, true);
		}
		delay(20);
	} else {
		send_key(code, 1);
		delay(10);
		send_key(code, 0);
	}
		macro_index++;
	return ;
}

// Clarity is important
void setup() {
	usbhid_init();
	pinMode(numlock_led, OUTPUT);
	digitalWrite(numlock_led, 0);
	for(uint8_t i = 0; i < sizeof(cols); i++)
		pinMode(cols[i], INPUT_PULLUP);
	for(uint8_t i = 0; i < sizeof(rows); i++) {
		pinMode(rows[i], OUTPUT);
		digitalWrite(rows[i], 1);
	}
	init_nvm_keymap();
	if (read_nvm_code(0, 0) != HID_KEYPAD_NUMLOCK)	
		numeric_keypad = false;
	wdt_enable(WDT_TIMEOUT);
}


void loop() {
	static uint8_t led_counter = 0;
	wdt_update();
	if (active_macro)
		type_macro_strings();
	scan();
	delay(10);	// scan interval.
	if (numeric_keypad) {
		if (get_hid_ledstate() & HID_LED_NUMLOCK)
			P1 |= NUMLOCK_LED_MASK;
		else
			P1 &= ~NUMLOCK_LED_MASK;
	} else {
		if (current_layer == 1)	// Fn layer on, light NumLock LED as indicator.
			P1 |= NUMLOCK_LED_MASK;
		else
			P1 &= ~NUMLOCK_LED_MASK;	
	}
}
